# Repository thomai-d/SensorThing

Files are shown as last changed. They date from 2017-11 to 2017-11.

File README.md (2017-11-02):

# SensorThing
ESP8266 + DHT22 RoomSensor

## Features
- Runs with 4x AA batteries (21µA Standby current => 1+ years runtime)
- Measures temperature, relative humidity and battery voltage
- Calculates dew point and absolute humidity
- Pushes data via HTTP POST to server

## Schematics
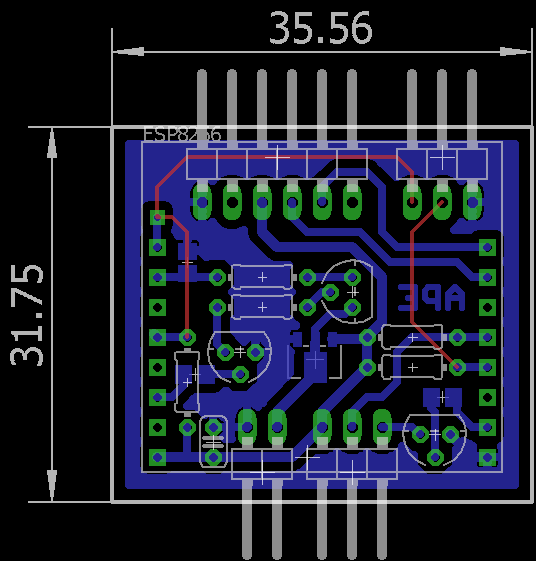
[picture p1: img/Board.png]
Board

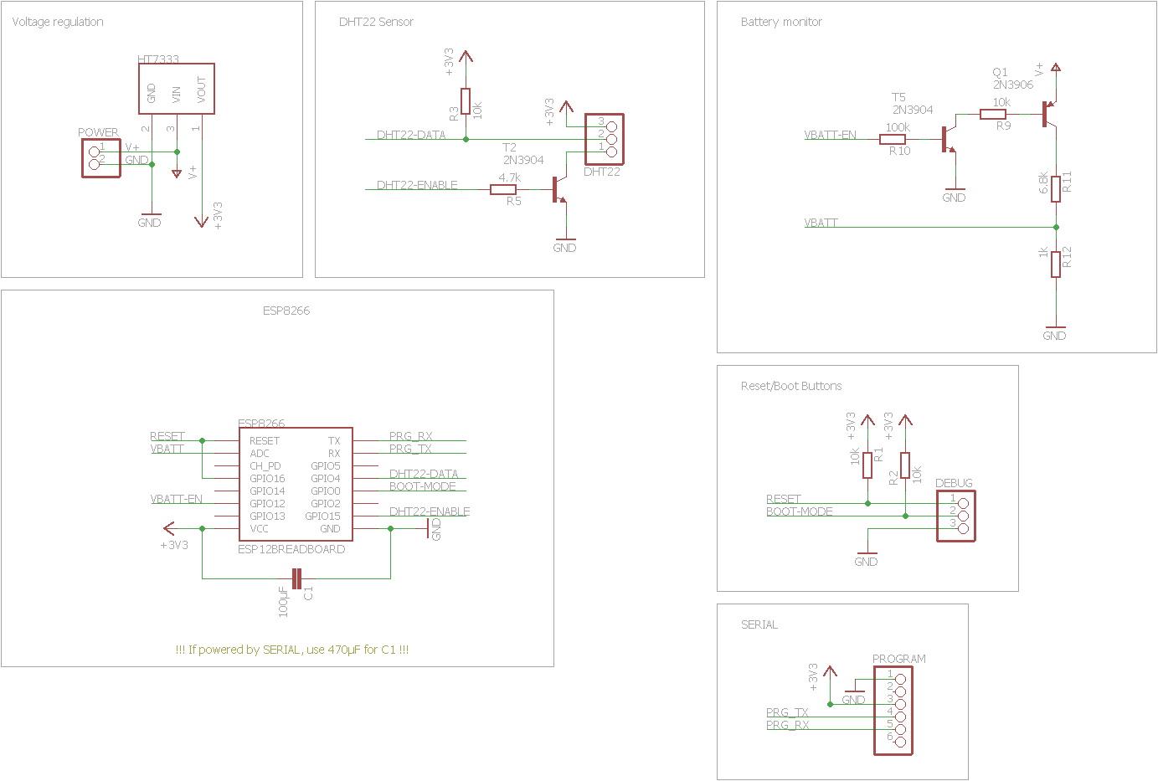
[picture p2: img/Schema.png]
Schematics


EAGLE files, see repository.

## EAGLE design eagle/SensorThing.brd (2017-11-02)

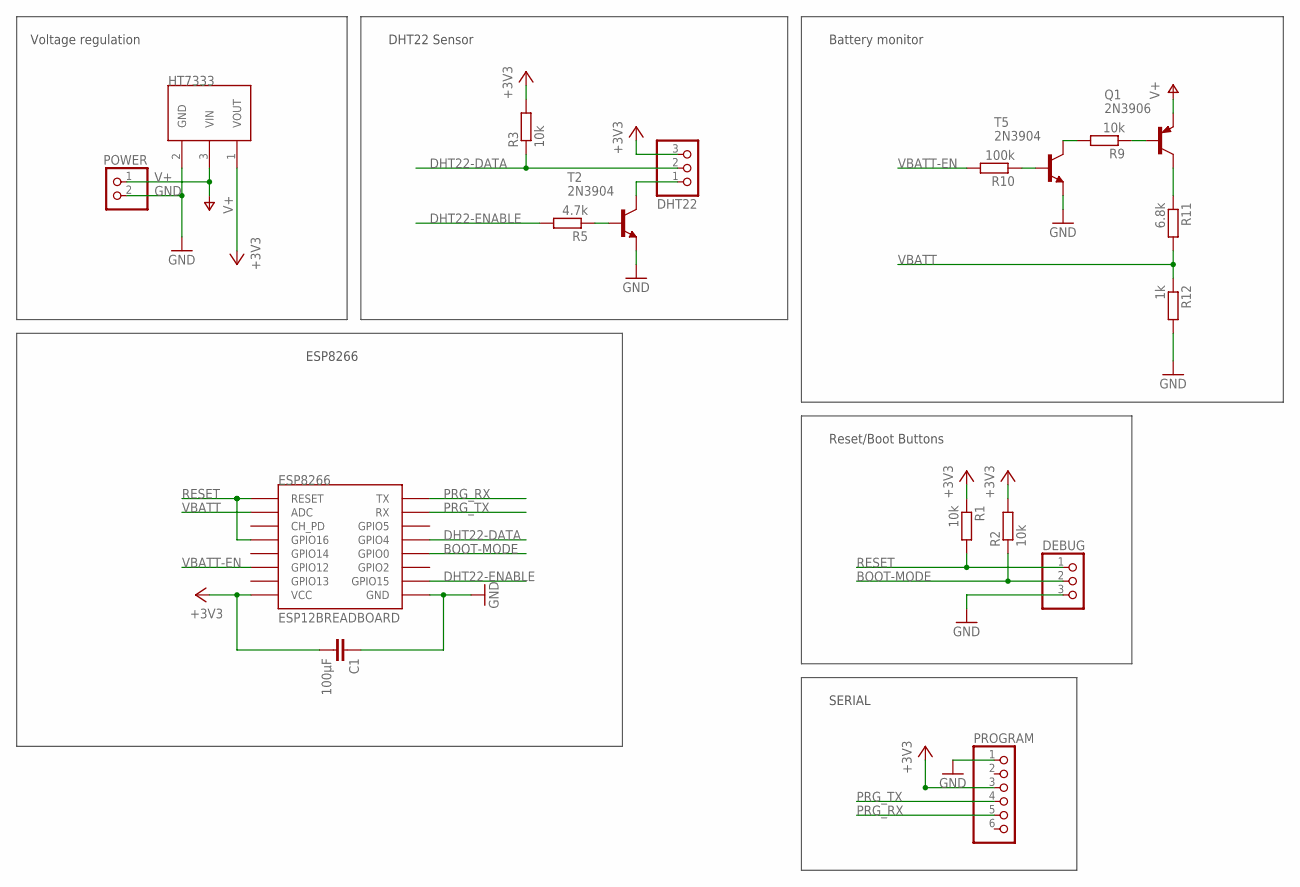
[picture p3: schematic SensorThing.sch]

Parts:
C1: 100µF; C025-024X044
DEBUG: 1X03/90
DHT22: 1X03/90
ESP8266: ESP12BREADBOARD; ESP12E-BREADBOARD
HT7333: HT73XX; SOT89-R
POWER: 1X02/90
PROGRAM: 1X06/90
Q1: 2N3906; TO92
R1, R2, R3, R9: 10k; 0204/7
R5: 4.7k; M0805
R10: 100k; M0805
R11: 6.8k; 0204/7
R12: 1k; M0805
T2, T5: 2N3904; TO92

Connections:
+3V3: C1.2, DHT22.3, ESP8266.8 (VCC), HT7333.1 (VOUT), PROGRAM.3, R1.1, R2.2, R3.2
BOOT-MODE: DEBUG.2, ESP8266.12 (GPIO0), R2.1
DHT22-DATA: DHT22.2, ESP8266.13 (GPIO4), R3.1
DHT22-ENABLE: ESP8266.10 (GPIO15), R5.2
GND: C1.1, DEBUG.3, ESP8266.9 (GND), HT7333.2 (GND), POWER.2, PROGRAM.1, R12.2, T2.3 (E), T5.3 (E)
unnamed: R5.1, T2.2 (B)
unnamed: DHT22.1, T2.1 (C)
unnamed: R9.2, T5.1 (C)
unnamed: R10.1, T5.2 (B)
unnamed: Q1.1 (C), R11.1
unnamed: Q1.2 (B), R9.1
PRG_RX: ESP8266.16 (TX), PROGRAM.5
PRG_TX: ESP8266.15 (RX), PROGRAM.4
RESET: DEBUG.1, ESP8266.1 (RESET), ESP8266.4 (GPIO16), R1.2
V+: HT7333.3 (VIN), POWER.1, Q1.3 (E)
VBATT: ESP8266.2 (ADC), R11.2, R12.1
VBATT-EN: ESP8266.6 (GPIO12), R10.2

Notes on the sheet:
Voltage regulation
DHT22 Sensor
Battery monitor
Reset/Boot Buttons
SERIAL
ESP8266

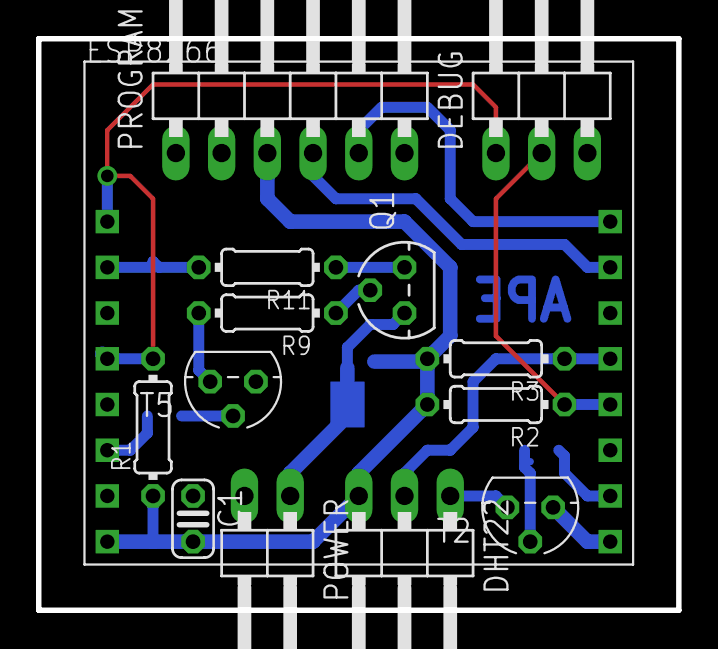
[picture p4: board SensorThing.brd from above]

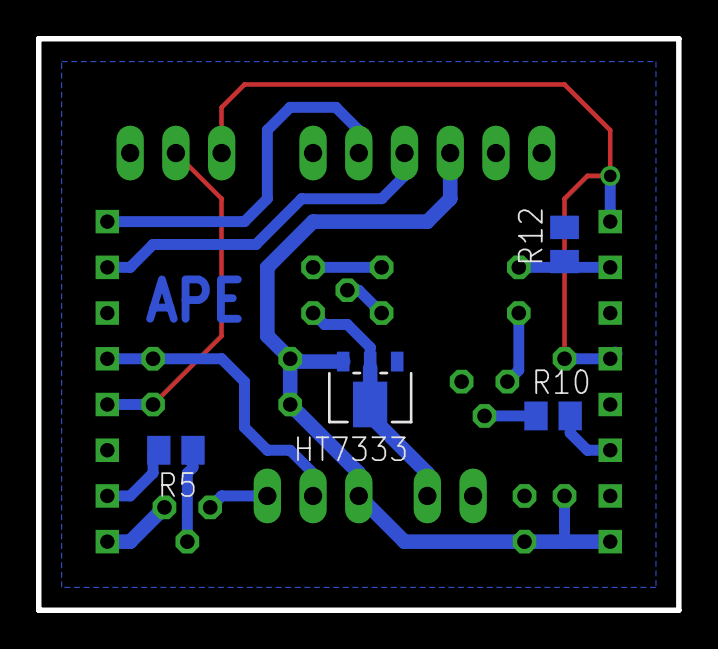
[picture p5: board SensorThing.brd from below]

Board: 2 copper layers, 35.6 x 31.8 mm, 18 parts (4 on the bottom side), 17 nets.

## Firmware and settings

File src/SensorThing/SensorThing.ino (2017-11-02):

// Dependencies
#include <ESP8266WiFi.h>
#include <user_interface.h>
#include "Math\Get.h"

// Abstractions
#include "Trace\Log.h"
#include "Configuration.h"
#include "Hardware\DHT22.h"
#include "Hardware\Wireless.h"
#include "Hardware\Voltmeter.h"
#include "Node\Node.h"

void GoDeepSleep(Error error)
{
	if (error > 0)
	{
		Serial.print("Error: ");
		Serial.println(error);
		
		blinkLed(error, 200);
	}
	else
	{
#ifdef DEBUG
		blinkLed(1, 500);
#endif
	}

	ESP.deepSleep(SLEEPTIME_US);
}

void blinkLed(int times, int duration)
{
	pinMode(2, OUTPUT);
	for (int n = 0; n < times; n++)
	{
		delay(duration);
		digitalWrite(2, LOW);
		delay(duration);
		digitalWrite(2, HIGH);
	}
	pinMode(2, INPUT);
}

void VBattEnable(bool enable)
{
	if (enable)
	{
		pinMode(VBATT_ENABLE_PIN, OUTPUT);
		digitalWrite(VBATT_ENABLE_PIN, HIGH);
	}
	else
	{
		digitalWrite(VBATT_ENABLE_PIN, LOW);
		pinMode(VBATT_ENABLE_PIN, INPUT);
	}
}

uint32_t start_millis;

void setup() {

	start_millis = millis();

	Log.Initialize();
	Log.println(F("Raumsensor V1"));

	DHT22.Enable();

	if (!Wireless.Connect())
	{
		DHT22.Disable();
		GoDeepSleep(Error::WirelessConnectFailed);
	}

	Log.println(F("Connecting to DHT22 ..."));
	uint8_t dhtReadFails = 0;
	while (!DHT22.Update())
	{
		Log.println(F("... retry"));
		dhtReadFails++;
		if (dhtReadFails == DHT22_RETRY_COUNT)
		{
			Log.println(F("ERROR: Communication with DHT22 failed!"));
			GoDeepSleep(Error::DHTReadFailed);
		}

		delay(DHT22_RETRY_DELAY_MS);
	}

	DHT22.Disable();

	float dewPoint		= DHT22.dewPoint;
	float humidity		= DHT22.humidity;
	float roomTemp		= DHT22.temperature;
	float absHumidity	= DHT22.absHumidity;
	VBattEnable(true);
	float voltage		= Voltmeter.Read();
	VBattEnable(false);

	Log.printfloat(F("Room-Temp:   "), roomTemp);
	Log.printfloat(F("Rel. Humid:  "), humidity);
	Log.printfloat(F("Abs. Humid:  "), absHumidity);
	Log.printfloat(F("DewPoint:    "), dewPoint);
	Log.printfloat(F("Voltage:     "), voltage);

	uint32_t now = millis();
	Node node;
	node.AddDataPoint("volt", voltage);
	node.AddDataPoint("temp", roomTemp);
	node.AddDataPoint("dewpoint", dewPoint);
	node.AddDataPoint("relhumid", humidity);
	node.AddDataPoint("abshumid", absHumidity);
	node.AddDataPoint("runtime", TIME_DELTA_MS(start_millis, now));

#ifdef DEBUG
	node.Post(NODE_DEBUG_HOST, NODE_PORT);
#else
	if (!node.Post(NODE_SERVER, NODE_PORT))
	{
		Log.print("Posting to ");
		Log.print(NODE_SERVER);
		Log.println(" failed.");
		GoDeepSleep(Error::PostToNodeFailed);
	}
#endif

	Log.print("Successfully posted to ");
	Log.println(NODE_SERVER);

	now = millis();
	Log.print("Total runtime: ");
	Log.println(TIME_DELTA_MS(start_millis, now));

	GoDeepSleep(Error::Ok);
}

void loop()
{
}

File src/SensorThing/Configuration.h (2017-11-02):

//#define DEBUG

#ifndef CONFIGURATION_H
#define CONFIGURATION_H

#include <stdint.h>

#define SERIAL_BAUD		74880

#ifdef DEBUG
#define SLEEPTIME_US	10 * 1000 * 1000
#else
#define SLEEPTIME_US	30 * 60 * 1000 * 1000
#endif

#define DHT22_PIN				4
#define DHT22_ENABLE_PIN		15			// HIGH = on, HIGH_IMP = off
#define VBATT_ENABLE_PIN		12			// HIGH = on, HIGH_IMP = off
#define SUCCESS_LED_PIN			14			// LOW = on, HIGH_IMP = off

#define DHT22_RETRY_COUNT		5
#define DHT22_RETRY_DELAY_MS	300

#define ADC_REF			1.0			// ADC reference voltage
#define ADC_PRECISION	10			// ADC precision bits
#define VOLTMETER_R1		6700.0
#define VOLTMETER_R2		999.0
#define VOLTMETER_OFFSET	0.028

extern const char*		WifiSSID;
extern const char*		WifiPass;

// HOME
#define WIFI_GATEWAY	IPAddress(192, 168, 0, 1)
#define WIFI_SUBNET		IPAddress(255, 255, 255, 0)
#define WIFI_DNS		IPAddress(192, 168, 0, 1)
#define WIFI_IP			IPAddress(192, 168, 0, 54)

#define NODE_SERVER		IPAddress(192, 168, 0, 10)
#define NODE_DEBUG_HOST	IPAddress(192, 168, 0, 20)
#define NODE_PORT		3007

// ERROR Codes

enum Error
{
	Ok = 0,
	DHTReadFailed = 1,
	WirelessConnectFailed = 2,
	PostToNodeFailed = 3,
};

#endif

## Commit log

2017-11-02 Added source code
    [Configuration.h]
2017-11-02 Added eagle files
    [SensorThing.brd, SensorThing.sch]
